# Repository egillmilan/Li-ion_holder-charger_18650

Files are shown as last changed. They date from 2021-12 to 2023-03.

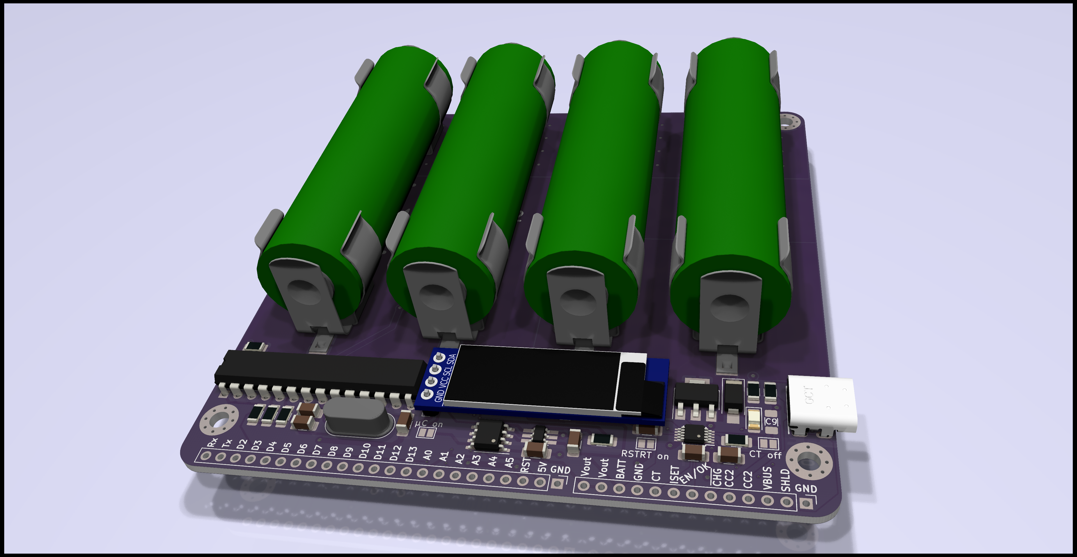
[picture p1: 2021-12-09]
Li-Ion_18650_charger.png

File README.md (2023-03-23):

# Li-ion_holder-charger_18650
A charger/holder for up to four 18650 lithium-ion battery cells. Charging current is a conservative 1A, regardless of how many cells are installed. This is due to the input being USB-C and the need for the device to be able to power whatever the batteries power while charging the batteries. The Ideal diode circuit switches the output to 5V from the USB if the charger is connected, otherwise the output comes from the li-ion cells.

**Some technical notes:**
<ul>
    <li>It is VERY important to only charge the same type of cells in parallel (same capacity and manufactuerer) and the cells need to have the same voltage when connected.</li>
    <li>If a charging timer is to be used, an appropriate capacity for C9 can be found in the datasheet and the RSTRT on jumper should be closed.</li>
    <li>C9 can be omitted if no charging timer is necessary, in that case close the CT off jumper.</li>
    <li>A 0.91" OLED and a dip-package ATmega328P can be added to monitor the voltage of the cells while charging, however this is not necessary for the circuit to function properly. If added, the µC on jumper should be closed.</li>
    <li>If no microcontroller is added, R8 can be ignored as it just acts as a pulldown for the ADC when no battery is connected.
    <li>The LED D1 can also be used to monitor the charging status.</li>
    <li>Watch polarity of cells when installed since there is no protection circuit.</li>
</ul>

Li-Ion_18650_charger

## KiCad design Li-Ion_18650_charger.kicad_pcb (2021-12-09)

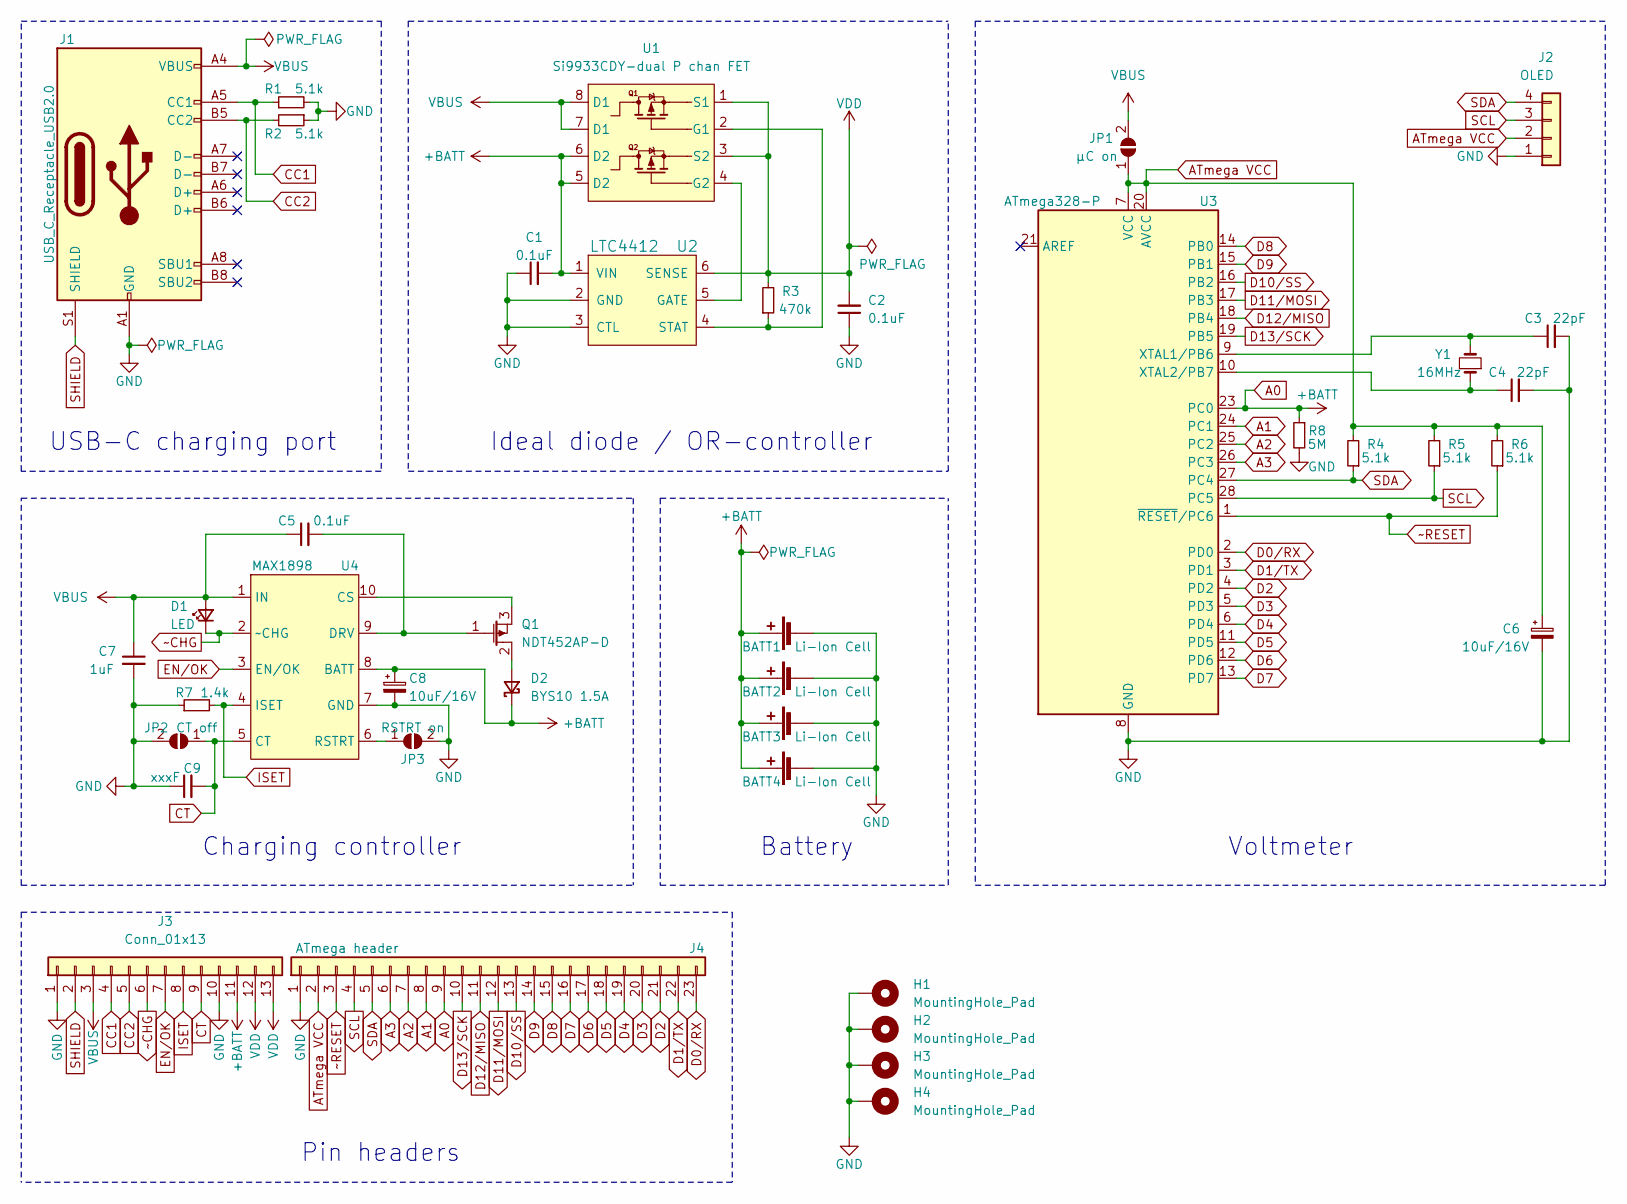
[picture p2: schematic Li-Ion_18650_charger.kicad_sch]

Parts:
BATT1, BATT2, BATT3, BATT4: Li-Ion Cell; Keystone_254_holder
C1, C2, C5: 0.1uF; C_1206_3216Metric_Pad1.33x1.80mm_HandSolder
C3, C4: 22pF; C_1206_3216Metric_Pad1.33x1.80mm_HandSolder
C6, C8: 10uF/16V; C_1206_3216Metric_Pad1.33x1.80mm_HandSolder
C7: 1uF; C_1206_3216Metric_Pad1.33x1.80mm_HandSolder
C9: xxxF; C_1206_3216Metric_Pad1.33x1.80mm_HandSolder
D1: LED; LED_1206_3216Metric_Pad1.42x1.75mm_HandSolder
D2: BYS10 1.5A; D_SMA_Handsoldering
H1, H2, H3, H4: MountingHole_Pad; MountingHole_3.2mm_M3_Pad_Via
J1: USB_C_Receptacle_USB2.0; GCT_USB4085-GF-A
J2: OLED; PinSocket_1x04_P2.54mm_Vertical
J3: Conn_01x13; PinHeader_1x13_P2.54mm_Vertical
J4: ATmega header; PinHeader_1x23_P2.54mm_Vertical
JP1: µC on; SolderJumper-2_P1.3mm_Open_Pad1.0x1.5mm
JP2: CT off; SolderJumper-2_P1.3mm_Open_Pad1.0x1.5mm
JP3: RSTRT on; SolderJumper-2_P1.3mm_Open_Pad1.0x1.5mm
Q1: NDT452AP-D; SOT-223-3_TabPin2
R1, R2, R4, R5, R6: 5.1k; R_1206_3216Metric_Pad1.30x1.75mm_HandSolder
R3: 470k; R_1206_3216Metric_Pad1.30x1.75mm_HandSolder
R7: 1.4k; R_1206_3216Metric_Pad1.30x1.75mm_HandSolder
R8: 5M; R_1206_3216Metric_Pad1.30x1.75mm_HandSolder
U1: Si9933CDY-dual P chan FET; SOIC-8_3.9x4.9mm_P1.27mm
U2: LTC4412; TSOT-23-6_HandSoldering; MPN LTC4412ES6#TRMPBF; Digi-Key_PN LTC4412ES6#TRMPBFCT-ND
U3: ATmega328-P; DIP-28_W7.62mm
U4: MAX1898; MSOP-10_3x3mm_P0.5mm
Y1: 16MHz; Crystal_HC49-4H_Vertical

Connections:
A1: J4.8, U3.24 (PC1)
A2: J4.7, U3.25 (PC2)
A3: J4.6, U3.26 (PC3)
ATmega VCC: C6.1, J2.2, J4.2, JP1.1 (A), R4.2, R5.2, R6.2, U3.7 (VCC), U3.20 (AVCC)
CC1: J1.A5 (CC1), J3.4, R1.1
CC2: J1.B5 (CC2), J3.5, R2.2
CT: C9.2, J3.9, JP2.1 (A), U4.5 (CT)
D0/RX: J4.23, U3.2 (PD0)
D1/TX: J4.22, U3.3 (PD1)
D2: J4.21, U3.4 (PD2)
D3: J4.20, U3.5 (PD3)
D4: J4.19, U3.6 (PD4)
D5: J4.18, U3.11 (PD5)
D6: J4.17, U3.12 (PD6)
D7: J4.16, U3.13 (PD7)
D8: J4.15, U3.14 (PB0)
D9: J4.14, U3.15 (PB1)
D10/SS: J4.13, U3.16 (PB2)
D11/MOSI: J4.12, U3.17 (PB3)
D12/MISO: J4.11, U3.18 (PB4)
D13/SCK: J4.10, U3.19 (PB5)
EN/OK: J3.7, U4.3 (EN/OK)
ISET: J3.8, R7.2, U4.4 (ISET)
unnamed: C3.1, U3.9 (XTAL1/PB6), Y1.2
unnamed: C4.1, U3.10 (XTAL2/PB7), Y1.1
unnamed: C5.2, Q1.1, U4.9 (DRV)
unnamed: D2.2 (A), Q1.2
unnamed: JP3.1 (A), U4.6 (RSTRT)
unnamed: Q1.3, U4.10 (CS)
unnamed: R3.1, U1.2 (G1), U2.4 (STAT)
unnamed: U1.4 (G2), U2.5 (GATE)
SCL: J2.3, J4.4, R5.1, U3.28 (PC5)
SDA: J2.4, J4.5, R4.1, U3.27 (PC4)
SHIELD: J1.S1 (SHIELD), J3.2
VBUS: C5.1, C7.1, D1.2 (A), J1.A4 (VBUS), J1.A9 (VBUS), J1.B4 (VBUS), J1.B9 (VBUS), J3.3, JP1.2 (B), U1.7 (D1), U1.8 (D1), U4.1 (IN)
VDD: C2.2, J3.12, J3.13, R3.2, U1.1 (S1), U1.3 (S2), U2.6 (SENSE)
~CHG: D1.1 (K), J3.6, U4.2 (~CHG)
~RESET: J4.3, R6.1, U3.1 (~RESET/PC6)

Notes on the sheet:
USB-C charging port
Charging controller
Pin headers
Ideal diode / OR-controller
Battery
Voltmeter

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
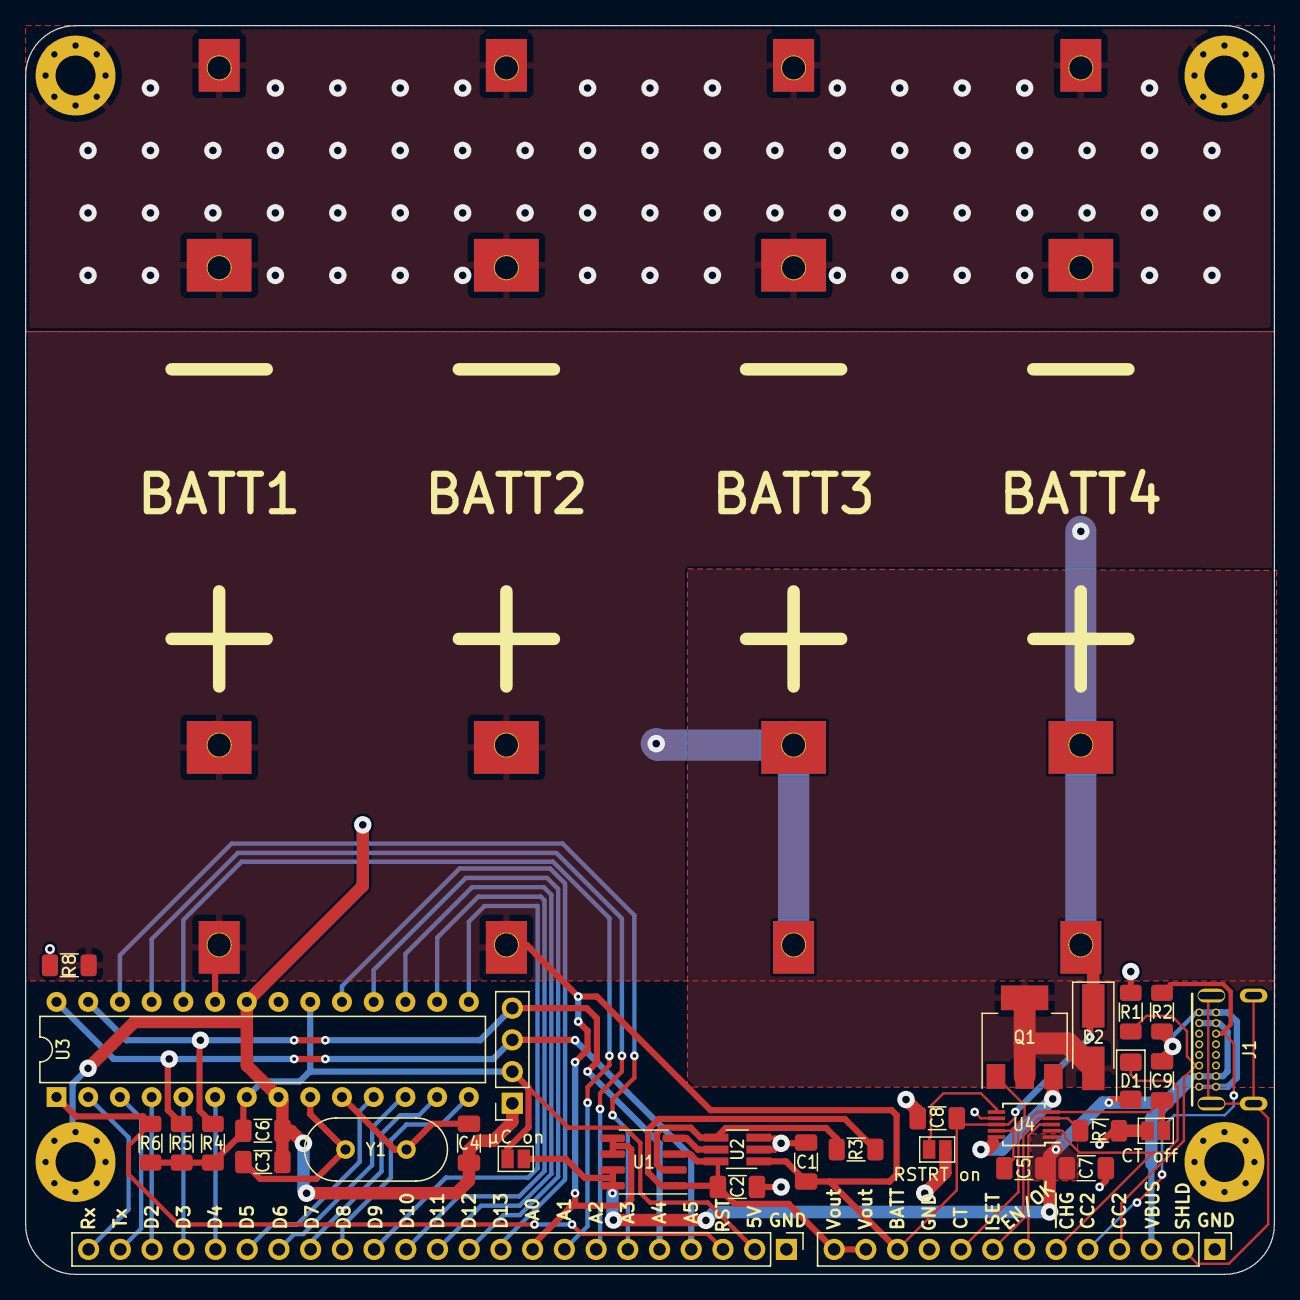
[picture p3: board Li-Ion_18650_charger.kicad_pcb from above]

Board: 2 copper layers, 100.0 x 100.0 mm, 40 parts (0 on the bottom side), 40 nets.
